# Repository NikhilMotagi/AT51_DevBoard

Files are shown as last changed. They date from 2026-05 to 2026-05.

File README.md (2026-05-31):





# AT51

Arduino Nano-style development board for the AT89S51 (8051-compatible) microcontroller.

AT51 is an open-source development board designed to bring the classic 8051 architecture into a modern, breadboard-friendly form factor. The project was created to showcase PCB design skills while providing a compact development platform for learning and experimenting with 8051-based microcontrollers.

<p align="center">
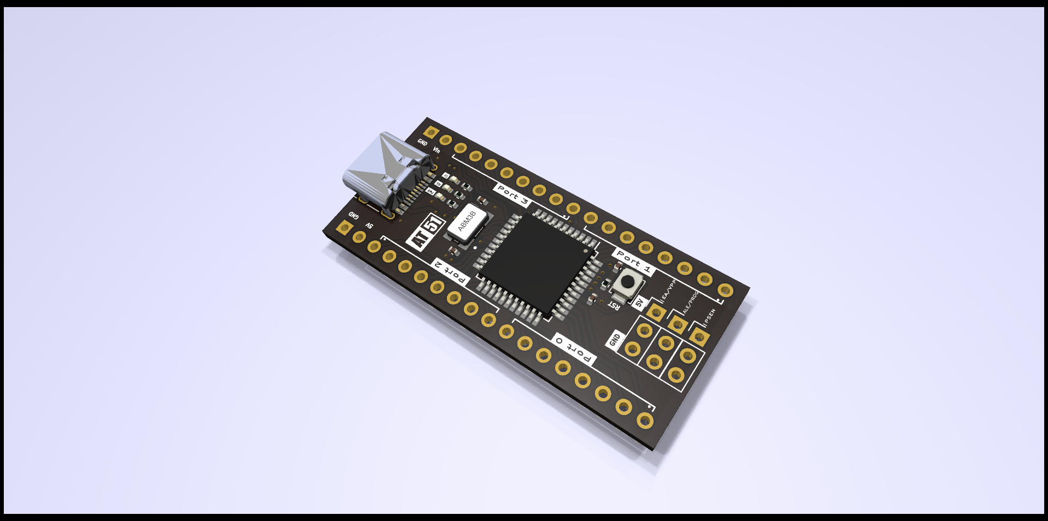
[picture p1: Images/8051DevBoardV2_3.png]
  
</p>

---

## Features

- Arduino Nano-inspired footprint
- Based on the AT89S51 microcontroller
- USB connectivity through FT232RL
- On-board programming interface
- Port-wise GPIO breakout
- Power status LED
- UART TX/RX activity LEDs
- Compact and breadboard-friendly layout

---

## Hardware Specifications

| Parameter | Value |
|---|---|
| MCU | AT89S51 |
| Architecture | 8051 Compatible |
| Operating Voltage | 5V |
| Clock Frequency | 11.0592 MHz |
| USB Interface | FT232RL |
| Form Factor | Arduino Nano Style |

---

## Design Goals

The objective of this project was to:

- Create a compact 8051 development platform
- Modernize the development experience for legacy microcontrollers
- Demonstrate PCB design and hardware integration skills
- Provide an open-source reference design for students and hobbyists

---

## Repository Contents

```text
/
├── Project File/
│   ├── Schematic Files
│   ├── PCB Layout
│
├── Gerbers/
│   └── Manufacturing Files
│
├── Images/
│
└── README.md
```

---

## Images

### PCB Render

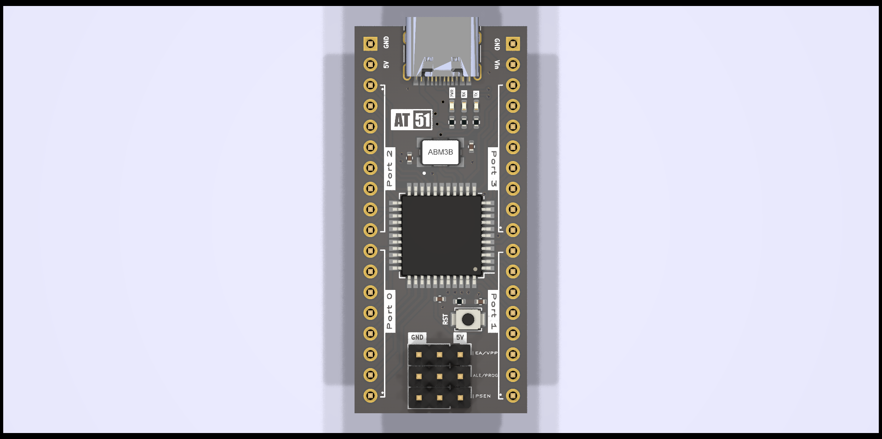
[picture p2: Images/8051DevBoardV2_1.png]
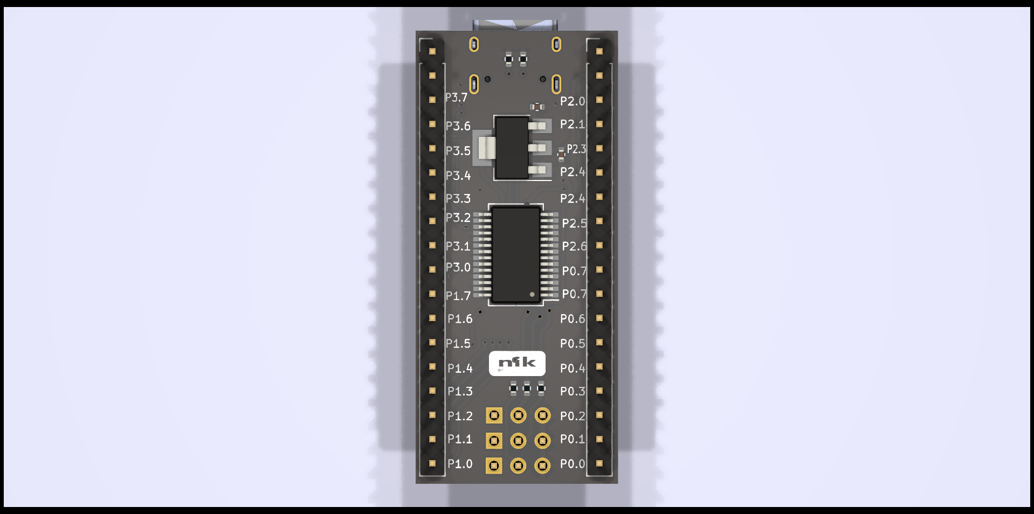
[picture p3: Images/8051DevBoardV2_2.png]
  |||
  |--|--|
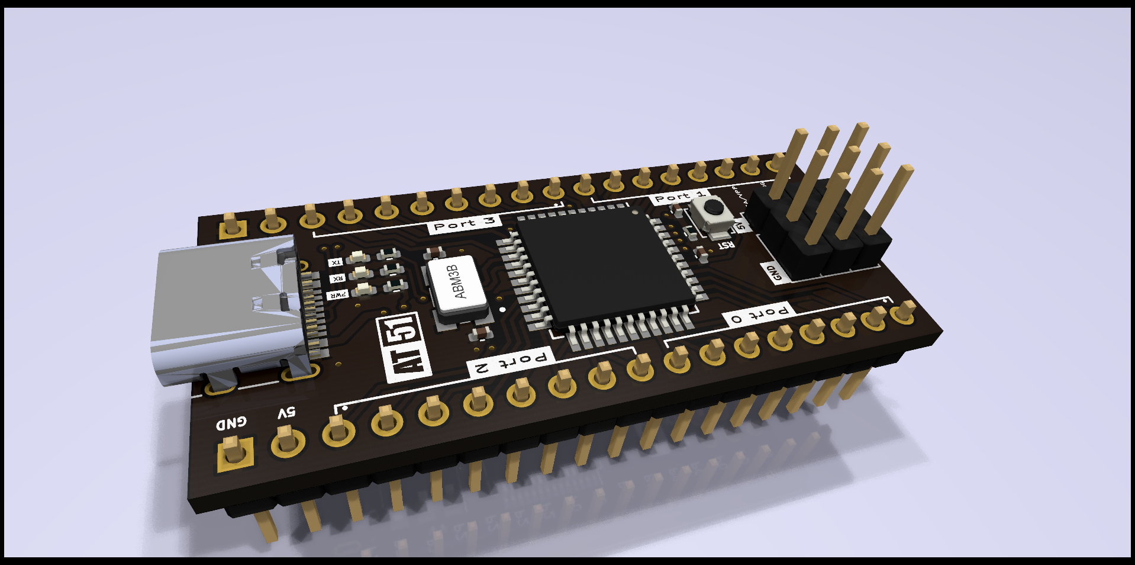
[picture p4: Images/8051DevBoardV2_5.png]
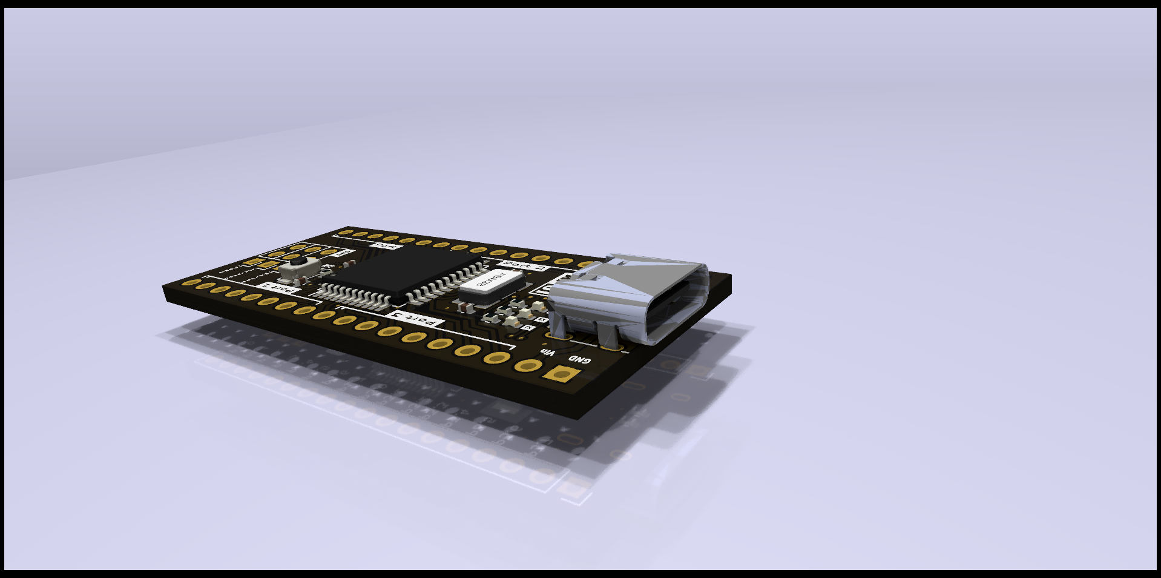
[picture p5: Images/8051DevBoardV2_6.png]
  |||

### Layout

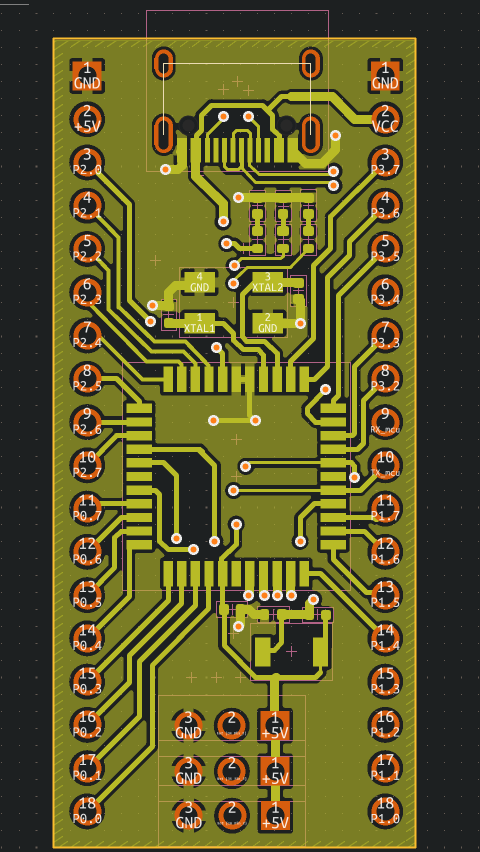
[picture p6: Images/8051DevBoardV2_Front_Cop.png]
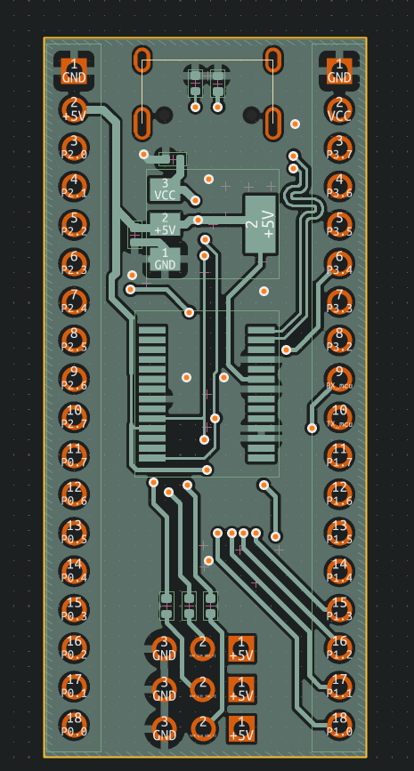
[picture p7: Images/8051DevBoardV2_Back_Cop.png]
|||
|--|--|

---

## Manufacturing Status

> ⚠️ Design Complete — Not Yet Manufactured

This repository currently contains the completed design files and manufacturing outputs. Physical prototypes have not yet been fabricated or tested.

---

## License

This project is released under the MIT License.

See the `LICENSE` file for details.

---

## Author

Designed by **Nikhil Motagi**.

If you find this project useful, feel free to star the repository and share your feedback.

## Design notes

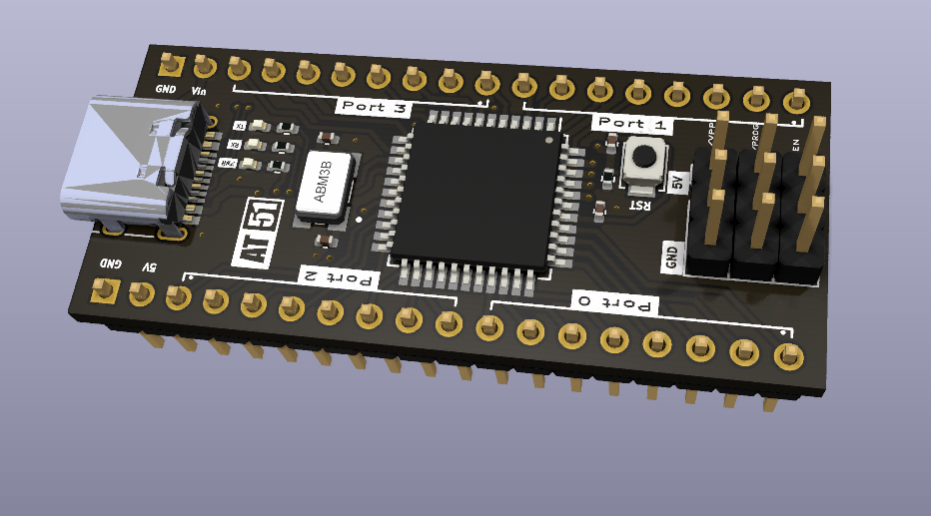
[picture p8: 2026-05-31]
Images/8051DevBoardV2_7.PNG

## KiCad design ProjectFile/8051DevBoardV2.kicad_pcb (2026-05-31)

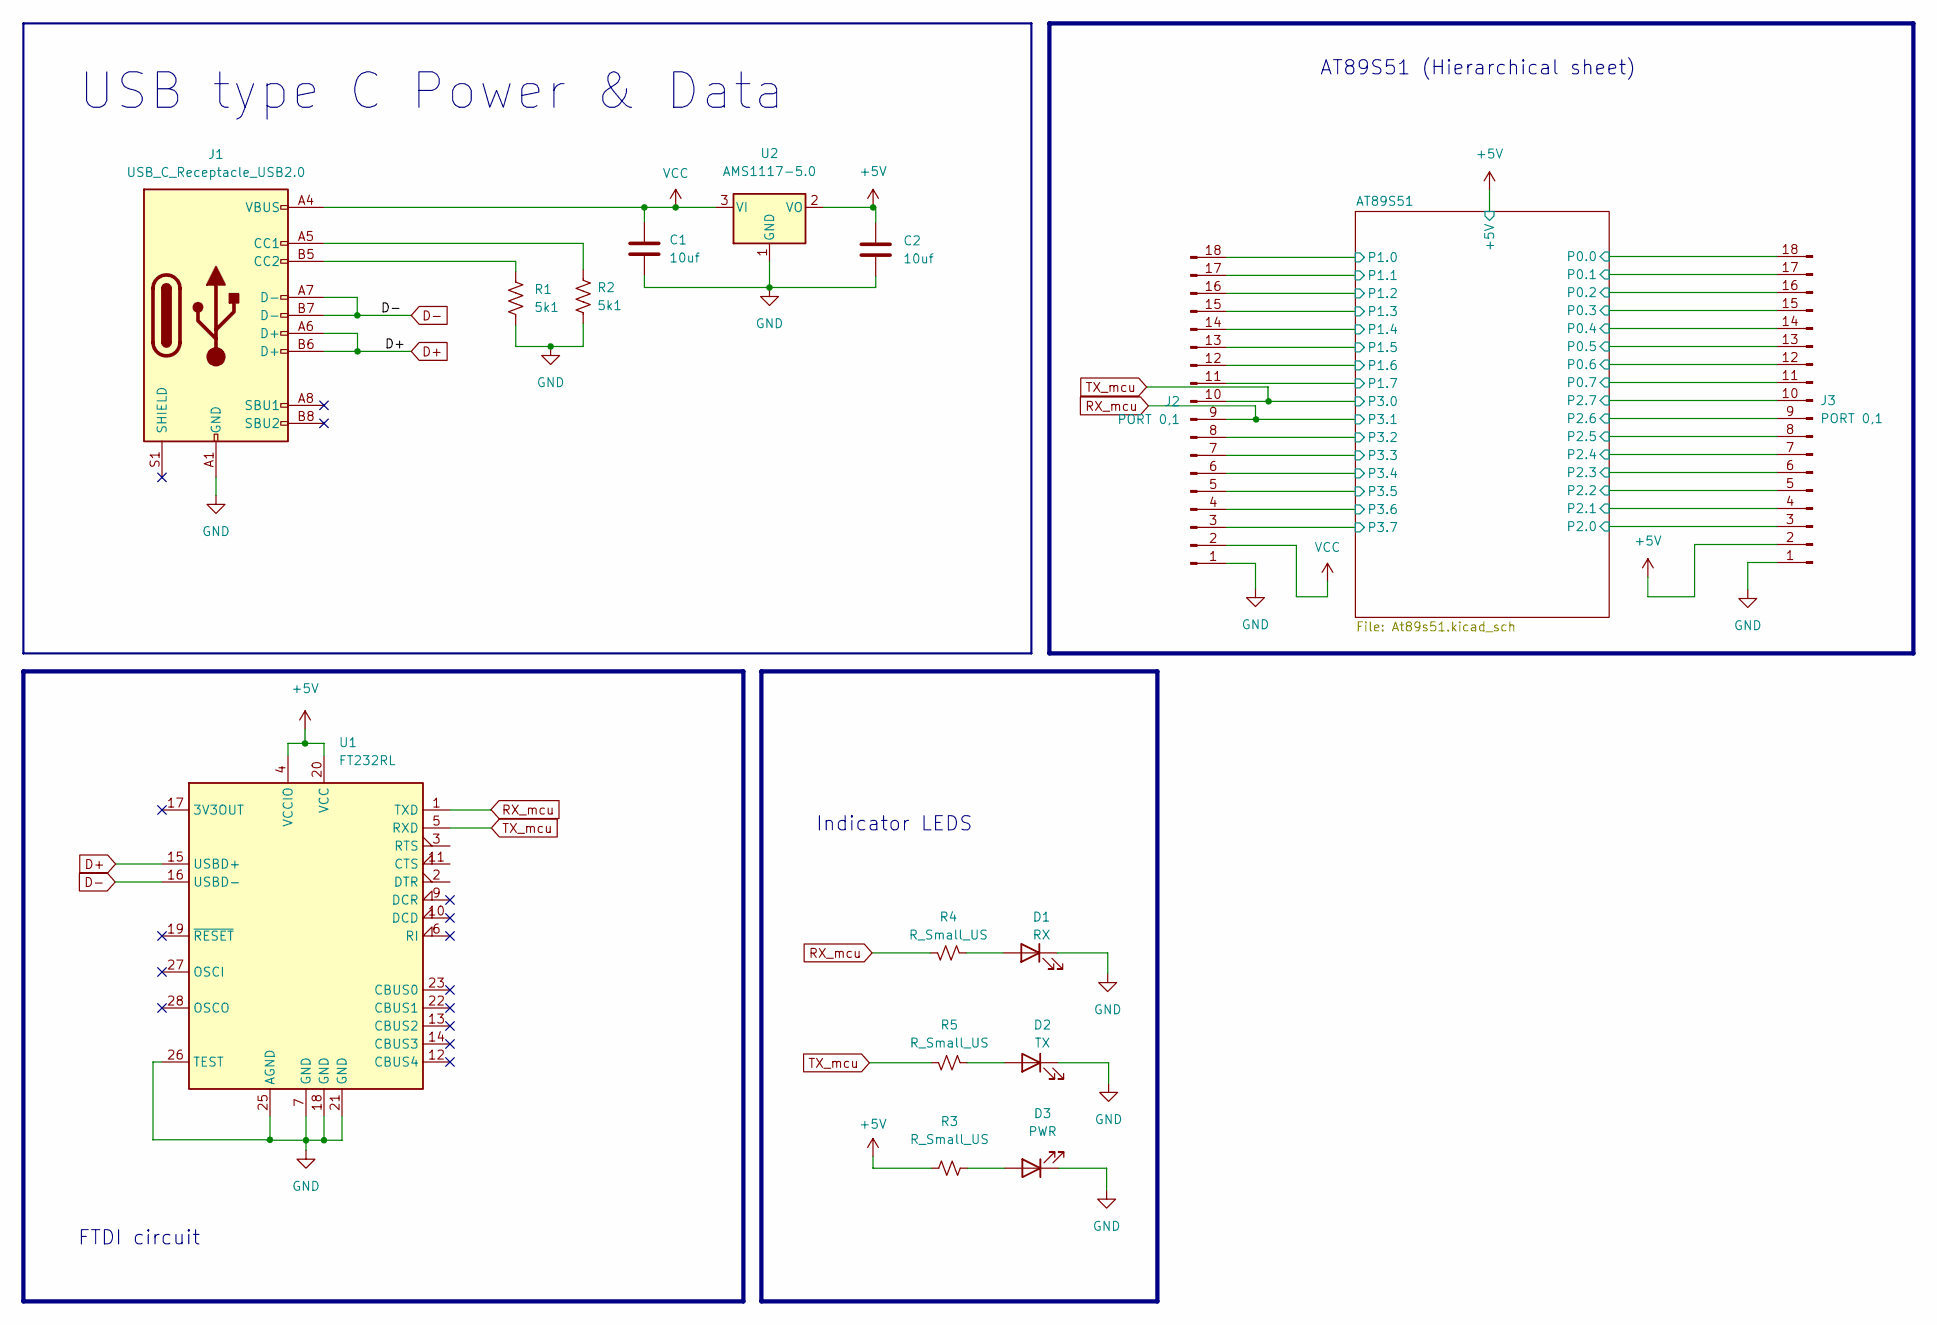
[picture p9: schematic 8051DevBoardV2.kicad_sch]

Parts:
C1, C2: 10uf; C_0402_1005Metric
D1: RX; LED_0402_1005Metric
D2: TX; LED_0402_1005Metric
D3: PWR; LED_0402_1005Metric
J1: USB_C_Receptacle_USB2.0; USB_C_Receptacle_HRO_TYPE-C-31-M-12
J2, J3: PORT 0,1; PinHeader_1x18_P2.54mm_Vertical
R1, R2: 5k1; R_0402_1005Metric
R3, R4, R5: R_Small_US; R_0402_1005Metric
U1: FT232RL; SSOP-28_5.3x10.2mm_P0.65mm
U2: AMS1117-5.0; SOT-223-3_TabPin2

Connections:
+5V: C2.1, J3.2, R3.1, U1.4 (VCCIO), U1.20 (VCC), U2.2 (VO); also elsewhere on the board
/AT89S51/P0.0: J3.18; also elsewhere on the board
/AT89S51/P0.1: J3.17; also elsewhere on the board
/AT89S51/P0.2: J3.16; also elsewhere on the board
/AT89S51/P0.3: J3.15; also elsewhere on the board
/AT89S51/P0.4: J3.14; also elsewhere on the board
/AT89S51/P0.5: J3.13; also elsewhere on the board
/AT89S51/P0.6: J3.12; also elsewhere on the board
/AT89S51/P0.7: J3.11; also elsewhere on the board
/AT89S51/P1.0: J2.18; also elsewhere on the board
/AT89S51/P1.1: J2.17; also elsewhere on the board
/AT89S51/P1.2: J2.16; also elsewhere on the board
/AT89S51/P1.3: J2.15; also elsewhere on the board
/AT89S51/P1.4: J2.14; also elsewhere on the board
/AT89S51/P1.5: J2.13; also elsewhere on the board
/AT89S51/P1.6: J2.12; also elsewhere on the board
/AT89S51/P1.7: J2.11; also elsewhere on the board
/AT89S51/P2.0: J3.3; also elsewhere on the board
/AT89S51/P2.1: J3.4; also elsewhere on the board
/AT89S51/P2.2: J3.5; also elsewhere on the board
/AT89S51/P2.3: J3.6; also elsewhere on the board
/AT89S51/P2.4: J3.7; also elsewhere on the board
/AT89S51/P2.5: J3.8; also elsewhere on the board
/AT89S51/P2.6: J3.9; also elsewhere on the board
/AT89S51/P2.7: J3.10; also elsewhere on the board
/AT89S51/P3.2: J2.8; also elsewhere on the board
/AT89S51/P3.3: J2.7; also elsewhere on the board
/AT89S51/P3.4: J2.6; also elsewhere on the board
/AT89S51/P3.5: J2.5; also elsewhere on the board
/AT89S51/P3.6: J2.4; also elsewhere on the board
/AT89S51/P3.7: J2.3; also elsewhere on the board
D+: J1.A6 (D+), J1.B6 (D+), U1.15 (USBD+)
D-: J1.A7 (D-), J1.B7 (D-), U1.16 (USBD-)
GND: C1.2, C2.2, D1.1 (K), D2.1 (K), D3.1 (K), J1.A1 (GND), J1.A12 (GND), J1.B1 (GND), J1.B12 (GND), J2.1, J3.1, R1.2, R2.2, U1.7 (GND), U1.18 (GND), U1.21 (GND), U1.25 (AGND), U1.26 (TEST), U2.1 (GND); also elsewhere on the board
unnamed: D1.2 (A), R4.2
unnamed: D2.2 (A), R5.2
unnamed: D3.2 (A), R3.2
unnamed: J1.A5 (CC1), R2.1
unnamed: J1.B5 (CC2), R1.1
RX_mcu: J2.9, R4.1, U1.1 (TXD); also elsewhere on the board
TX_mcu: J2.10, R5.1, U1.5 (RXD); also elsewhere on the board
VCC: C1.1, J1.A4 (VBUS), J1.A9 (VBUS), J1.B4 (VBUS), J1.B9 (VBUS), J2.2, U2.3 (VI)

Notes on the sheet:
AT89S51 (Hierarchical sheet)
FTDI circuit
USB type C Power & Data
Indicator LEDS

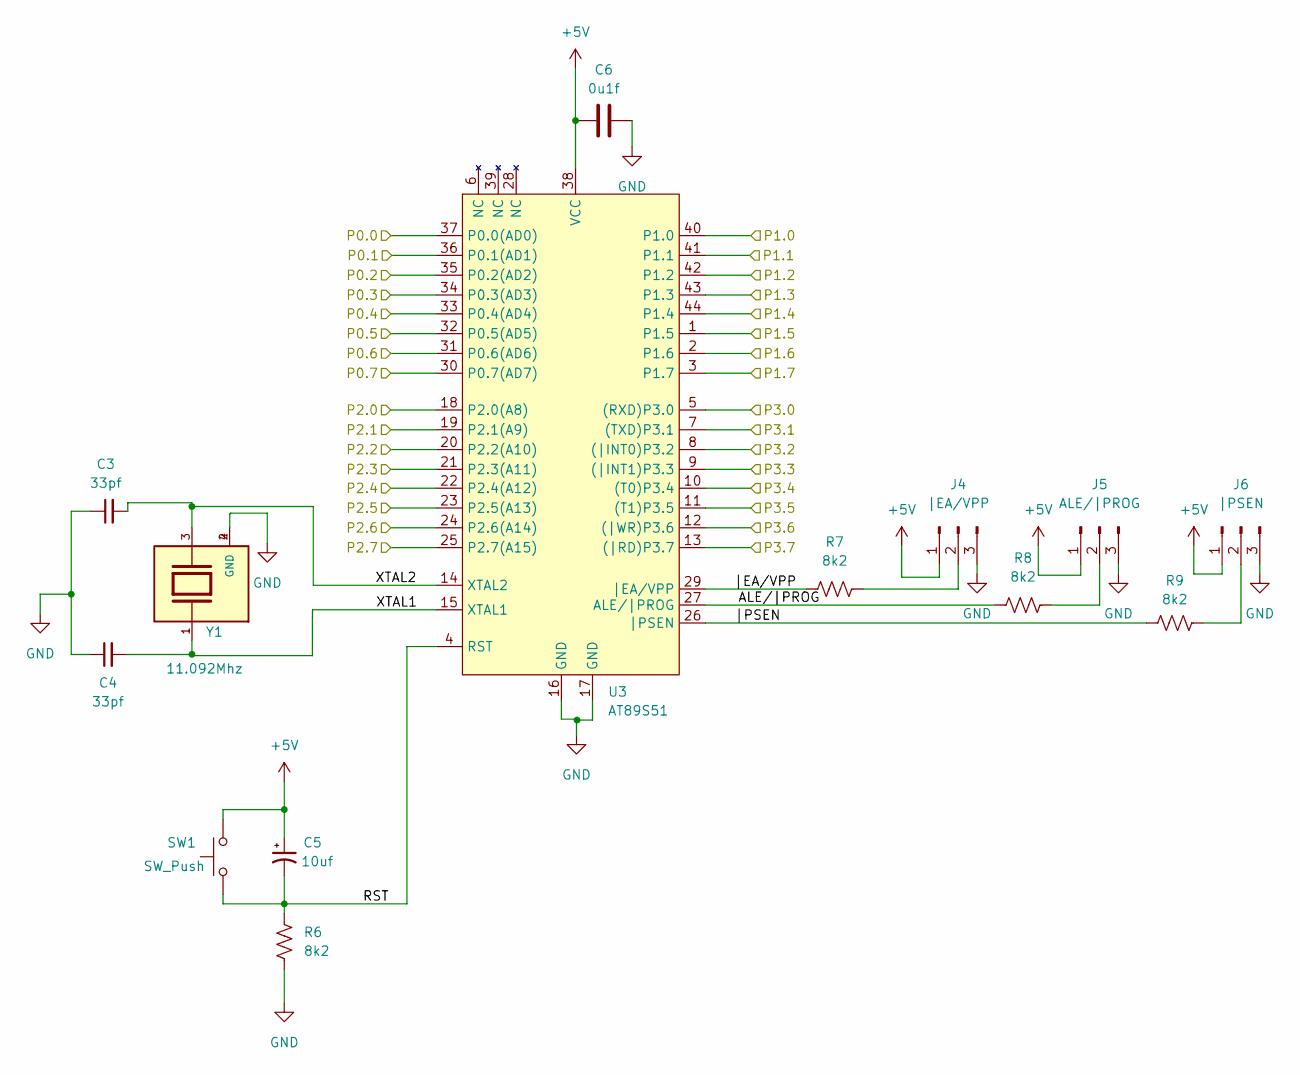
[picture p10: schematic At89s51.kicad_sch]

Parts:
C3, C4: 33pf; C_0402_1005Metric
C5: 10uf; C_0402_1005Metric
C6: 0u1f; C_0402_1005Metric
J4: |EA/VPP; PinHeader_1x03_P2.54mm_Vertical
J5: ALE/|PROG; PinHeader_1x03_P2.54mm_Vertical
J6: |PSEN; PinHeader_1x03_P2.54mm_Vertical
R6, R7, R8, R9: 8k2; R_0402_1005Metric
SW1: SW_Push; SW_SPST_B3U-1000P
U3: AT89S51; TQFP-44_10x10mm_P0.8mm
Y1: 11.092Mhz; XTAL_ABM3B-11.0592MHZ-10-1-U-T; PARTREV 08.25.15

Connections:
+5V: C5.1, C6.1, J4.1, J5.1, J6.1, SW1.2, U3.38 (VCC); also elsewhere on the board
/AT89S51/ALE/|PROG: R8.1, U3.27 (ALE/|PROG)
/AT89S51/P0.0: U3.37 (P0.0(AD0)); also elsewhere on the board
/AT89S51/P0.1: U3.36 (P0.1(AD1)); also elsewhere on the board
/AT89S51/P0.2: U3.35 (P0.2(AD2)); also elsewhere on the board
/AT89S51/P0.3: U3.34 (P0.3(AD3)); also elsewhere on the board
/AT89S51/P0.4: U3.33 (P0.4(AD4)); also elsewhere on the board
/AT89S51/P0.5: U3.32 (P0.5(AD5)); also elsewhere on the board
/AT89S51/P0.6: U3.31 (P0.6(AD6)); also elsewhere on the board
/AT89S51/P0.7: U3.30 (P0.7(AD7)); also elsewhere on the board
/AT89S51/P1.0: U3.40 (P1.0); also elsewhere on the board
/AT89S51/P1.1: U3.41 (P1.1); also elsewhere on the board
/AT89S51/P1.2: U3.42 (P1.2); also elsewhere on the board
/AT89S51/P1.3: U3.43 (P1.3); also elsewhere on the board
/AT89S51/P1.4: U3.44 (P1.4); also elsewhere on the board
/AT89S51/P1.5: U3.1 (P1.5); also elsewhere on the board
/AT89S51/P1.6: U3.2 (P1.6); also elsewhere on the board
/AT89S51/P1.7: U3.3 (P1.7); also elsewhere on the board
/AT89S51/P2.0: U3.18 (P2.0(A8)); also elsewhere on the board
/AT89S51/P2.1: U3.19 (P2.1(A9)); also elsewhere on the board
/AT89S51/P2.2: U3.20 (P2.2(A10)); also elsewhere on the board
/AT89S51/P2.3: U3.21 (P2.3(A11)); also elsewhere on the board
/AT89S51/P2.4: U3.22 (P2.4(A12)); also elsewhere on the board
/AT89S51/P2.5: U3.23 (P2.5(A13)); also elsewhere on the board
/AT89S51/P2.6: U3.24 (P2.6(A14)); also elsewhere on the board
/AT89S51/P2.7: U3.25 (P2.7(A15)); also elsewhere on the board
/AT89S51/P3.2: U3.8 ((|INT0)P3.2); also elsewhere on the board
/AT89S51/P3.3: U3.9 ((|INT1)P3.3); also elsewhere on the board
/AT89S51/P3.4: U3.10 ((T0)P3.4); also elsewhere on the board
/AT89S51/P3.5: U3.11 ((T1)P3.5); also elsewhere on the board
/AT89S51/P3.6: U3.12 ((|WR)P3.6); also elsewhere on the board
/AT89S51/P3.7: U3.13 ((|RD)P3.7); also elsewhere on the board
/AT89S51/RST: C5.2, R6.1, SW1.1, U3.4 (RST)
/AT89S51/XTAL1: C4.2, U3.15 (XTAL1), Y1.1
/AT89S51/XTAL2: C3.2, U3.14 (XTAL2), Y1.3
/AT89S51/|EA/VPP: R7.1, U3.29 (|EA/VPP)
/AT89S51/|PSEN: R9.1, U3.26 (|PSEN)
GND: C3.1, C4.1, C6.2, J4.3, J5.3, J6.3, R6.2, U3.16 (GND), U3.17 (GND), Y1.2 (GND), Y1.4 (GND); also elsewhere on the board
unnamed: J4.2, R7.2
unnamed: J5.2, R8.2
unnamed: J6.2, R9.2
RX_mcu: U3.7 ((TXD)P3.1); also elsewhere on the board
TX_mcu: U3.5 ((RXD)P3.0); also elsewhere on the board

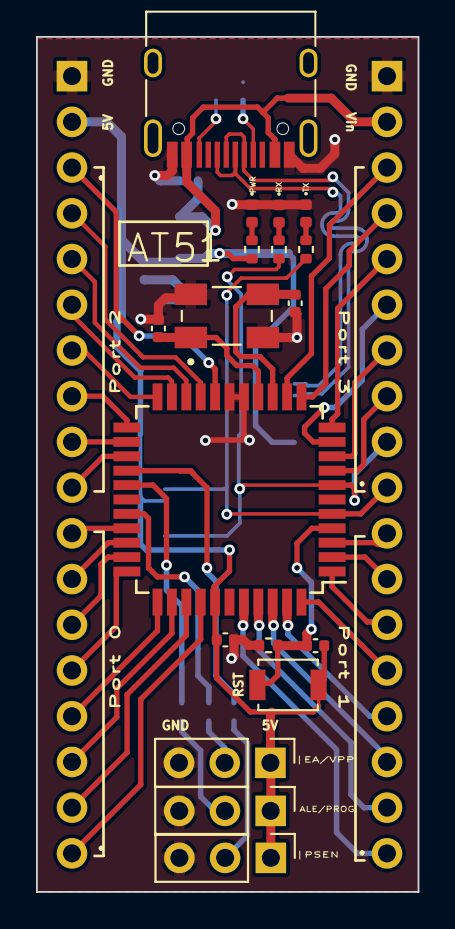
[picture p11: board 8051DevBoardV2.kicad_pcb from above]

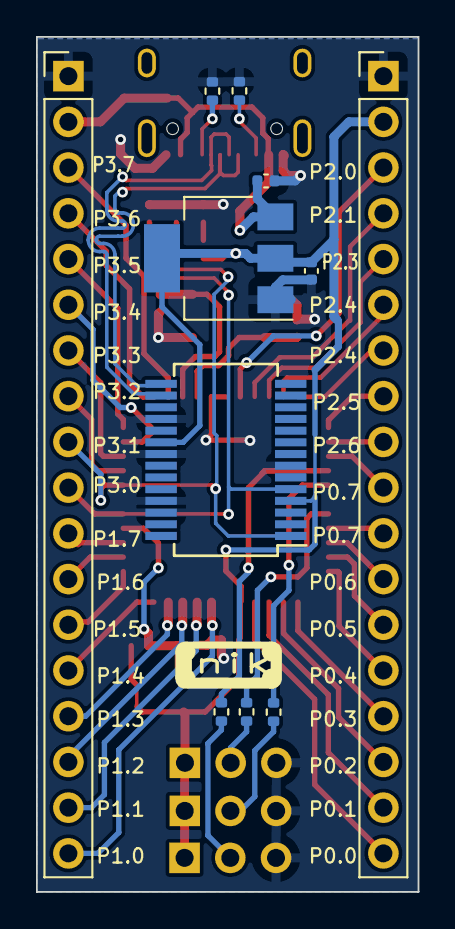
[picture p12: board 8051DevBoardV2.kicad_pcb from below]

Board: 2 copper layers, 21.2 x 47.5 mm, 29 parts (11 on the bottom side), 51 nets.

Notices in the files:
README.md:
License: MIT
